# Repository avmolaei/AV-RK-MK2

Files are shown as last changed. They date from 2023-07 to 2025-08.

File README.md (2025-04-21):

# AV-RK-MK2

The AV-RK MK II is the second iteration of the AVlabs [AV-RK MK I](https://github.com/avmolaei/AV-RK-MK1), the AVlabs "Redox Styled" Mechanical Keyboard.
![AV-RK MK 2](img/1.png

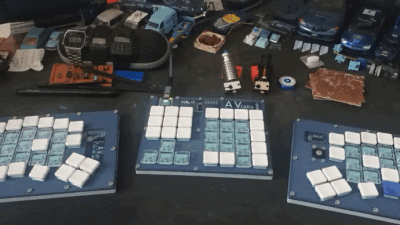
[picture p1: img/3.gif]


The AV-RK MK II uses a 3D printed body, Kailh Choc Switches and is based on a XIAO SAMD21 board. There is only one MCU running the whole thing: switches are connected to IO expanders (PCA9505), that share an I2C bus, which is propagated through magnetic pogo pins (like the Apple MagSafe connector). 
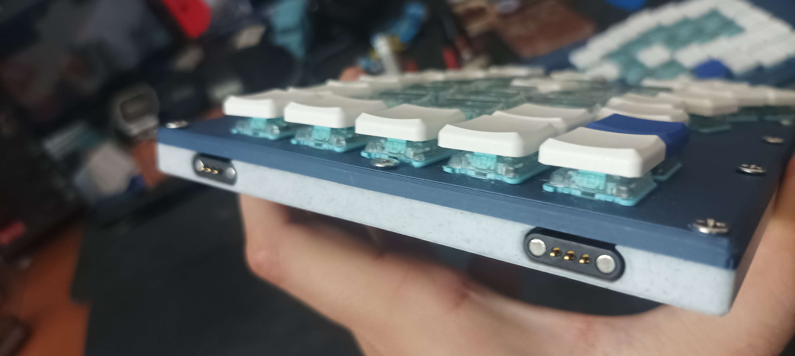
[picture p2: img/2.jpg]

The goal was also to make an even thinner keyboad than the MK I for more comfort: 
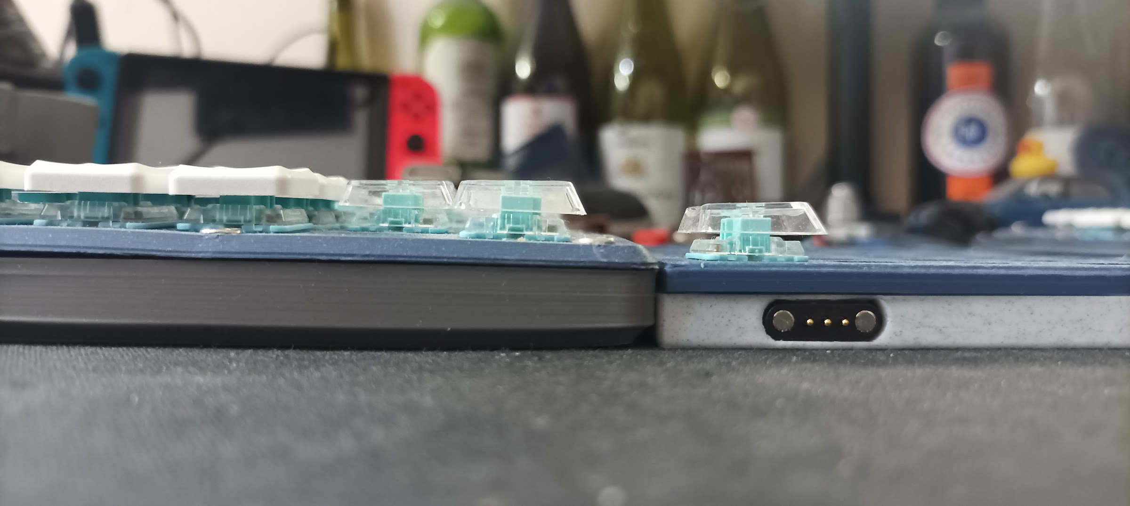
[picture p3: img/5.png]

(the MK I on the left, and the MK II on the right)
  
The [AV-RK-MK I](https://github.com/avmolaei/AV-RK-MK1) and the [AV-KO1](https://github.com/avmolaei/AV-KO1/) are both handwired keyboards (Expaination in details in the AV-KO1 repo). While handwire is easy to get started on, it has a few problems:

 - The switches are held to the top plate with nothing but friction, and over time (especially if you use "tall" switch+keycap combos, the switch can get loose, or if you knock the board it can get the switch to "pop out":
 - 
 - If you don't plan out your tolerances and screw holes correctly, the top plate will "bow", and make a gap between the plate and body as there is nothing to keep it from bowig
 - Soldering 100 switches and diodes is a good exercise but it is a bit tedious...
 - As most shift registers/IO Expanders are small SMD parts, most "sane" Handwire builds have multiple microcontrôleurs, which is not always ideal. 

The 3 parts connect together with cool magnetic pogo pins. these pogo pins allow a modular layout, i.e if the pogo pins are wired identically and laid out symetrically, you can put the numpad on the left, in the middle, on the right, or even add modules: as long as it communicates with I2C. The architecture of the AV-RK-MK2 is as follows:
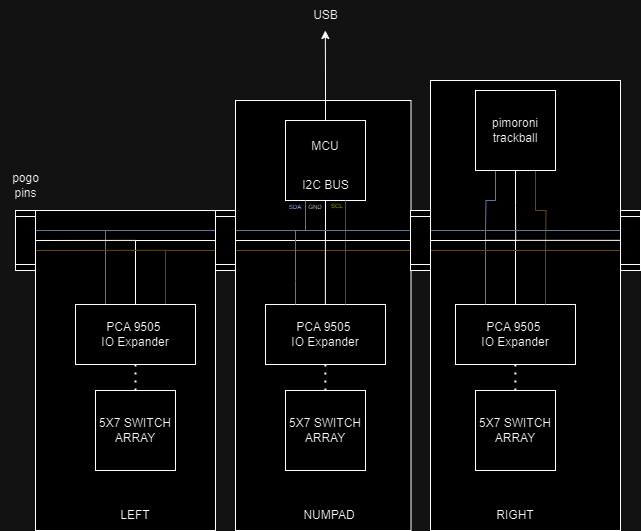
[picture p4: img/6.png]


 Here the goal was to design and build my "endgame" definition of a keyboard. It had to be "redox styled", it had to have kailh choc robins, and it had to have PCBs!
 
 Indeed, while PCBs do imply a higher cost, they make assembly super simple and allow for more complex layout! The PCA9505 couldn't have been used without the PCBS. As our keyboard has 3 parts, it has 3 PCBs:
 

The PCBs are pretty simple: they are just a bunch of switches connected to the PCA input pins, and the PCA's I2C line being distributed to pins which will be connected to the pogo pins. The middle PCB (numpad) has a small cutout for the XIAO board, and the right PCB has a cutout made to fit a pimoroni trackball, or any other I2C device you would want. 

Available below are:

CAD files: Fusion 360 source and STLs for 3D printed parts

FIRMWARE: the arudino code that runs the keyboard

PCB files: gerbers and boms

MODULES: modules, duh.

`//TODO: shit to fix and/or add
`

PCBs: on all PCBs, the I2C/PWR lines are too close to the edge. On the right PCB, the pins for the pimoroni trackball are reversed, which requires an annoying bodge.

Technically speaking, I2C is not rated for hot swap. In a future iteration, the PCBs **SHOULD** integrate a TCA4307 from TI, a simple I2C buffer to allow for a less buggy kb if the stack is moved from arduino to TinyUSB/from scratch

FIRMWARE: needs to be ported from SAMD21 core to NRF52840. Also, need to fix trackball precision issue. Also, the USB HID lib needs to go from Keyboard.h to TinyUSB.

CAD: maybe enhance aesthetics for the top plate? also need to make some sort of alignement system for the pogo pins, sometimes when docking/undocking modules the pins may short and require a MCU reset

`MODULES:`

**__AV-RK SENSOR MODULE__**: It has a thin OLED display and a square one. It will have an RTC, a humidity/temp sensor and a heartbeat sensor, all that on the I2C BUS. V2 of this module will inclue an independant MCU so the code is not cluttering the main keyboard code. AAAAAAAAA

**__AV-RK MOUSE CHARGER__**: it will have a tiny arduino nano inside, and will recieve commands based on keyboard shortcuts on the I2C bus. The "independant" arduino will trigger LEDs for caps lock/num lock/scroll lock, and will control a tiny servo-actuated arm that shows pogo pins to charge the mouse overnight. The mouse needs to be modified with a USB connector soldered to pogo pins. 

Sensors have been designed, made; all is left is to integrate them in the main code. 

A better, more sensible solution would be to embedd a small low power MCU (e.g: arduino nano) in each module, and make them use a "protocol", where Fn + [NUMPAD NUMBER] sends a set command and the module is programmed to understand the command, instead of integrating everything in the main keyboard code, making a messs. 
2025: i kinda forgot about the modules, after 1 yeaer and half. The only one that sees regular use is the mouse charger.

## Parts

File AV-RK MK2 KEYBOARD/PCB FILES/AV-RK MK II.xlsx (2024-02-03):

where to get the shit | cost
Keycaps and switches (splitkb.com) | 131.41 €
MCU board, pogo pins, and other shit (amazon) | 148.74 €
3D printer filament (amazon) | 45.00 €
LCSC/JLCPCB: numpad | 92.32 €
LCSC/JLCPCB: left + right | 183.43 €
TOTAL | 600.90 €

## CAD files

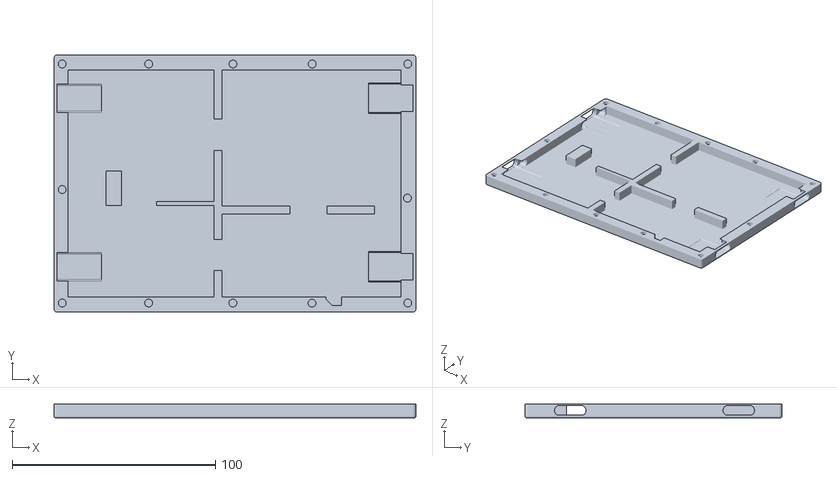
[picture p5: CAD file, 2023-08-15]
AV-RK MK2 KEYBOARD/CAD FILES/AV_RK_MK_II_CAD/left/v2/bottom (1).stl
178.3 x 126.7 x 7.00

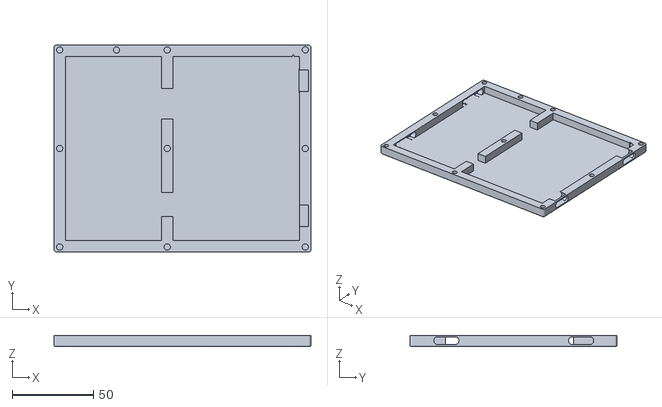
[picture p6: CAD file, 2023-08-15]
AV-RK MK2 KEYBOARD/CAD FILES/AV_RK_MK_II_CAD/numpad/stl/v2/bottom.stl
158.3 x 127.5 x 7.00

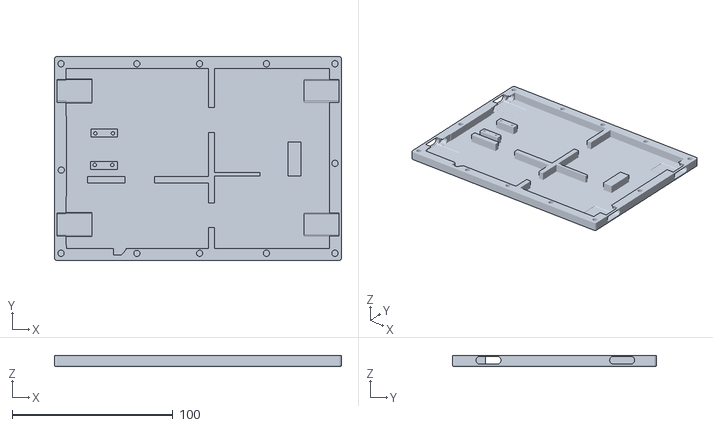
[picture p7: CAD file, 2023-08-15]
AV-RK MK2 KEYBOARD/CAD FILES/AV_RK_MK_II_CAD/right/v2/bottom.stl
178.3 x 126.7 x 7.00

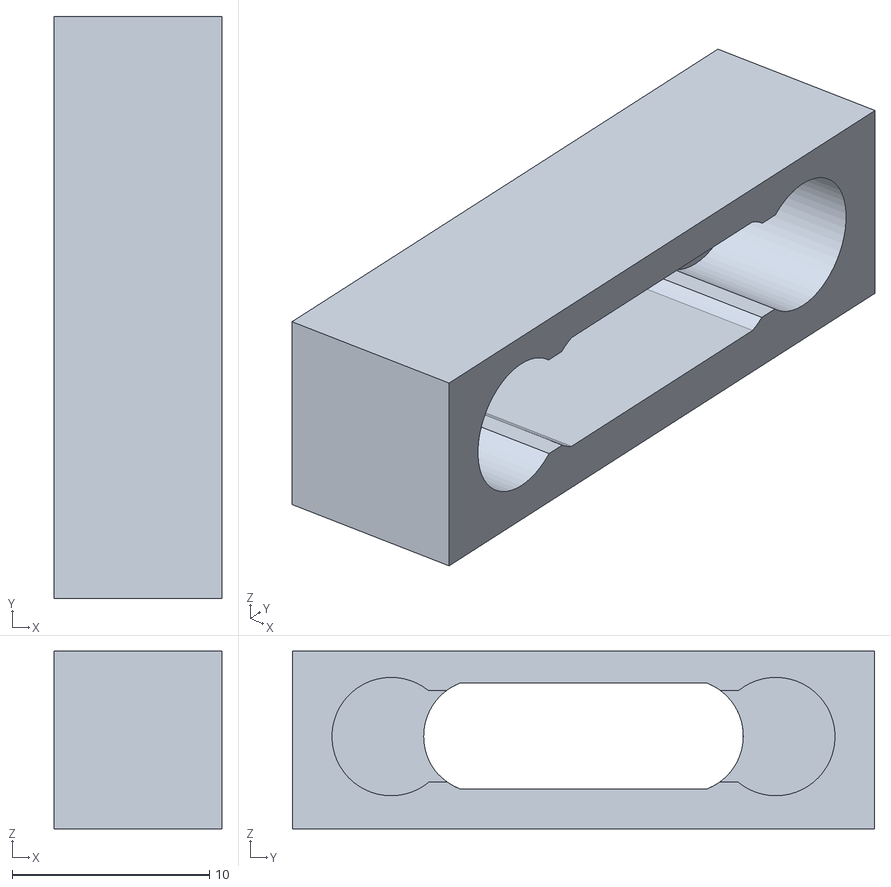
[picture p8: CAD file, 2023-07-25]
AV-RK MK2 KEYBOARD/CAD FILES/tests/Corps42.stl
8.50 x 29.5 x 9.00

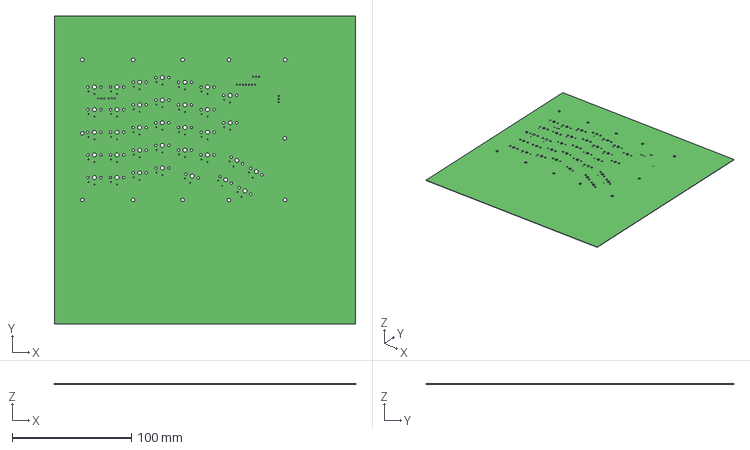
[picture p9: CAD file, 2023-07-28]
AV-RK MK2 KEYBOARD/PCB FILES/LEFT/EDA FILES/Altium/left.step
252.9 x 258.6 x 0.411 mm

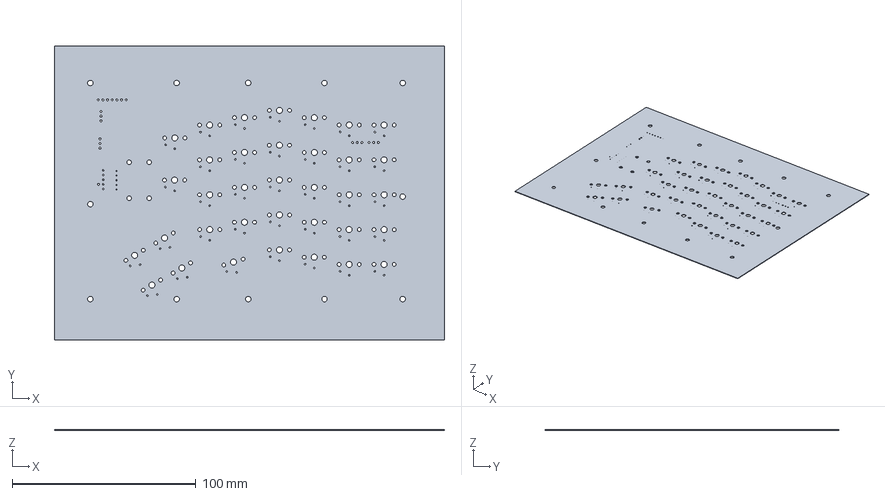
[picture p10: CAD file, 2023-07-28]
AV-RK MK2 KEYBOARD/PCB FILES/RIGHT/EDA FILES/Altium/PCB_RIGHT_AV-RK MK II_2023-07-27.step
212.5 x 160.2 x 0.411 mm

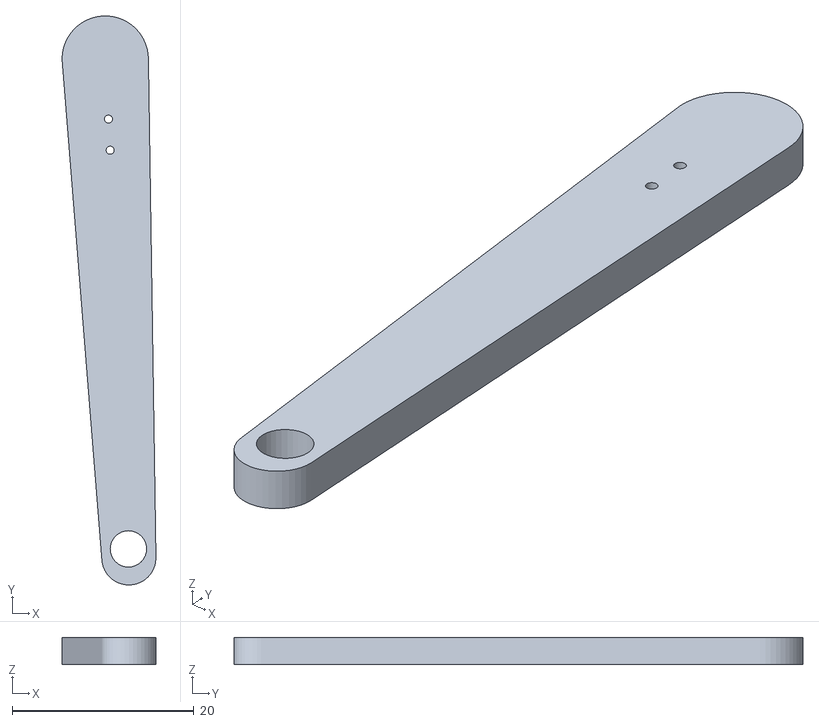
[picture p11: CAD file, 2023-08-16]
AV-RK MK2 MODULE - MOUSE CHARGER/CAD FILES/link.stl
10.3 x 62.6 x 3.00

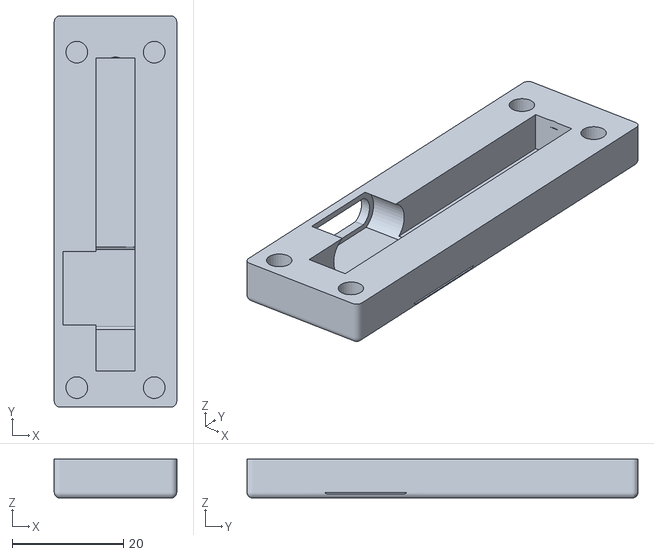
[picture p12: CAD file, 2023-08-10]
AV-RK MK2 MODULE - MOUSE CHARGER/CAD FILES/mouse pogo pin adapter/moving part/bottom.stl
22.0 x 70.2 x 7.00

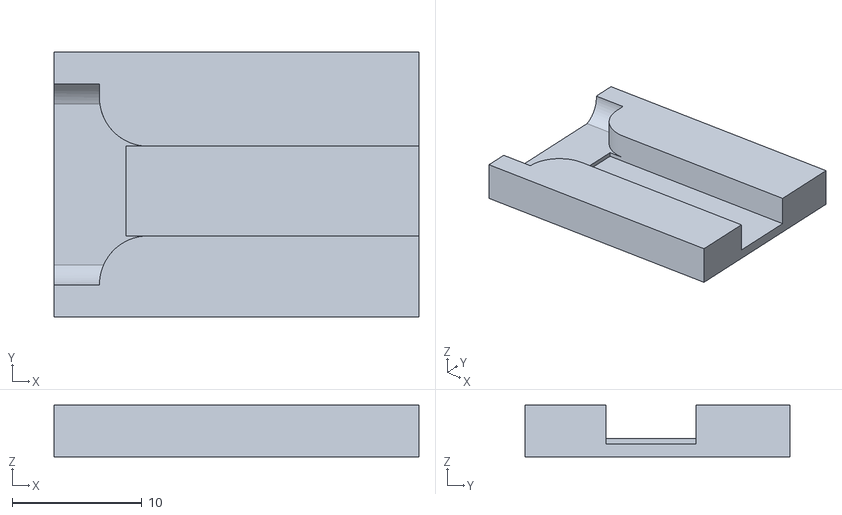
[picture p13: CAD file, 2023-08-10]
AV-RK MK2 MODULE - MOUSE CHARGER/CAD FILES/mouse pogo pin adapter/top.stl
28.1 x 20.4 x 4.00

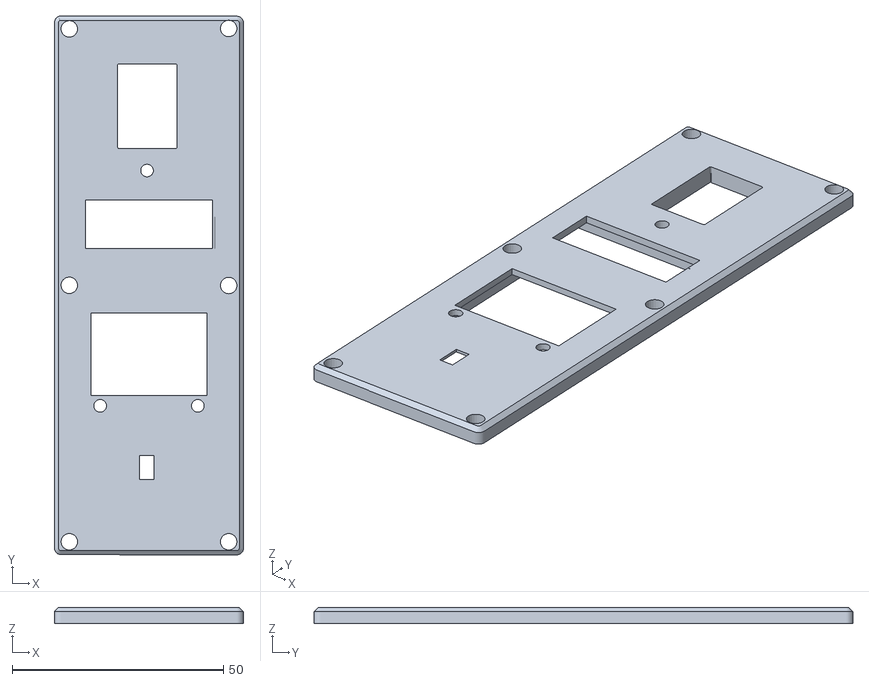
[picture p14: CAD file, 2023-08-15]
AV-RK MK2 MODULE - SENSOR SCREEN/3D PRINTED PARTS/GCODE/top (3).stl
44.7 x 127.4 x 3.80

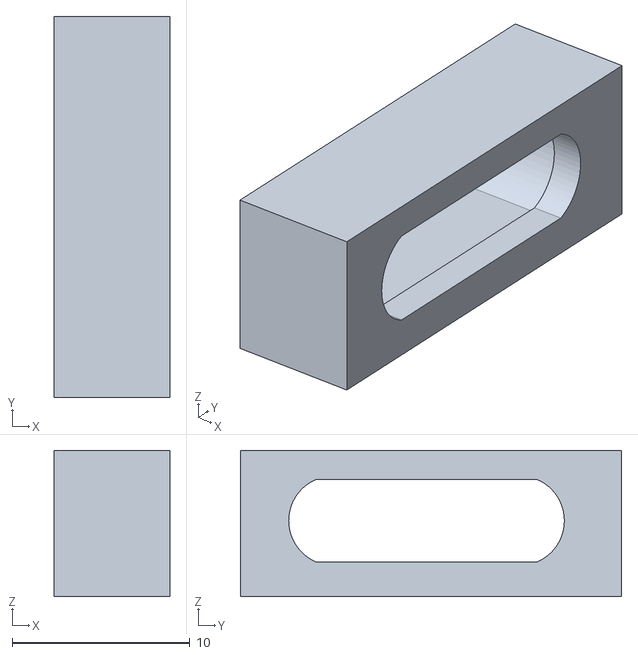
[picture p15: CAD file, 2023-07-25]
AV-RK MK2 KEYBOARD/CAD FILES/tests/test pogo.stl
6.50 x 21.4 x 8.21

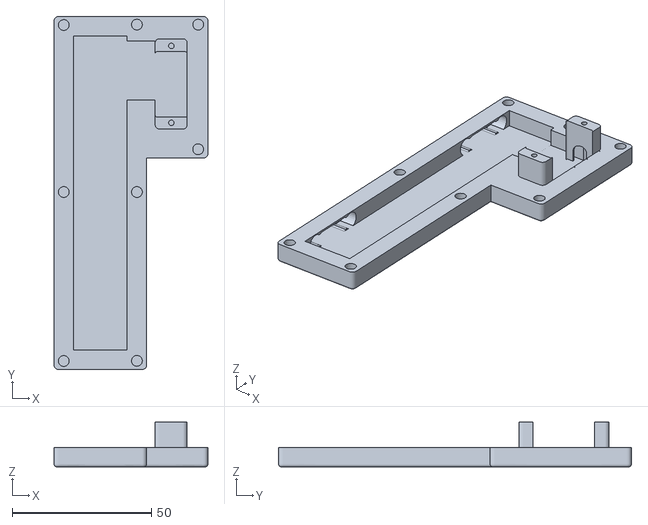
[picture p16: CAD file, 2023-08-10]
AV-RK MK2 MODULE - MOUSE CHARGER/CAD FILES/bottom (3).stl
55.2 x 126.7 x 16.0

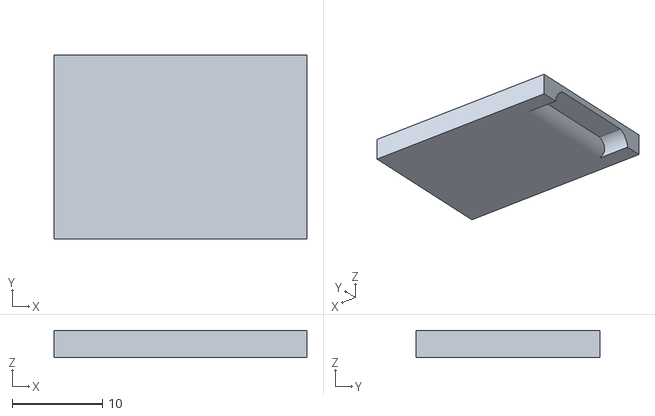
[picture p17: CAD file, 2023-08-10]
AV-RK MK2 MODULE - MOUSE CHARGER/CAD FILES/mouse pogo pin adapter/bottom (2).stl
28.1 x 20.4 x 3.00

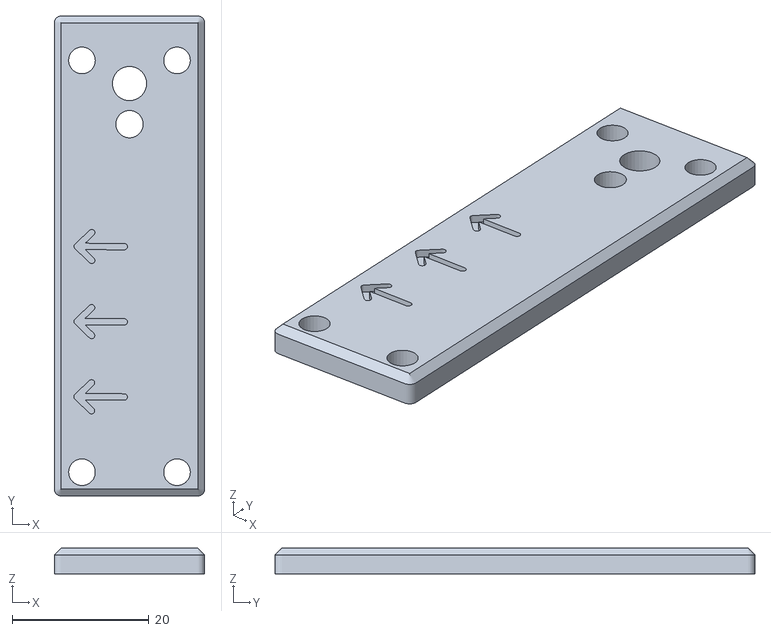
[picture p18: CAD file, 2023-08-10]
AV-RK MK2 MODULE - MOUSE CHARGER/CAD FILES/mouse pogo pin adapter/moving part/TOP.stl
22.0 x 70.2 x 3.80

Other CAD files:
AV-RK MK2 MODULE - SENSOR SCREEN/3D PRINTED PARTS/STL/TOP.stl
AV-RK MK2 MODULE - SENSOR SCREEN/3D PRINTED PARTS/top (3).stl
AV-RK MK2 MODULE - SENSOR SCREEN/3D PRINTED PARTS/STL/BOTTOM.stl
AV-RK MK2 KEYBOARD/CAD FILES/tests/test pogo m.stl
AV-RK MK2 KEYBOARD/CAD FILES/AV_RK_MK_II_CAD/left/v1/bottom (1).stl
AV-RK MK2 KEYBOARD/CAD FILES/AV_RK_MK_II_CAD/left/v1/left drawing.dxf
AV-RK MK2 KEYBOARD/CAD FILES/AV_RK_MK_II_CAD/left/v1/top (1).stl
AV-RK MK2 KEYBOARD/CAD FILES/AV_RK_MK_II_CAD/left/v1/top window.stl
AV-RK MK2 KEYBOARD/CAD FILES/AV_RK_MK_II_CAD/numpad/stl/v1/bottom.stl
AV-RK MK2 KEYBOARD/CAD FILES/AV_RK_MK_II_CAD/numpad/stl/v1/top.stl
AV-RK MK2 KEYBOARD/CAD FILES/AV_RK_MK_II_CAD/right/v1/bottom (1) (1).stl
AV-RK MK2 KEYBOARD/CAD FILES/AV_RK_MK_II_CAD/right/v1/top (1) (1).stl
AV-RK MK2 MODULE - MOUSE CHARGER/CAD FILES/top (2).stl

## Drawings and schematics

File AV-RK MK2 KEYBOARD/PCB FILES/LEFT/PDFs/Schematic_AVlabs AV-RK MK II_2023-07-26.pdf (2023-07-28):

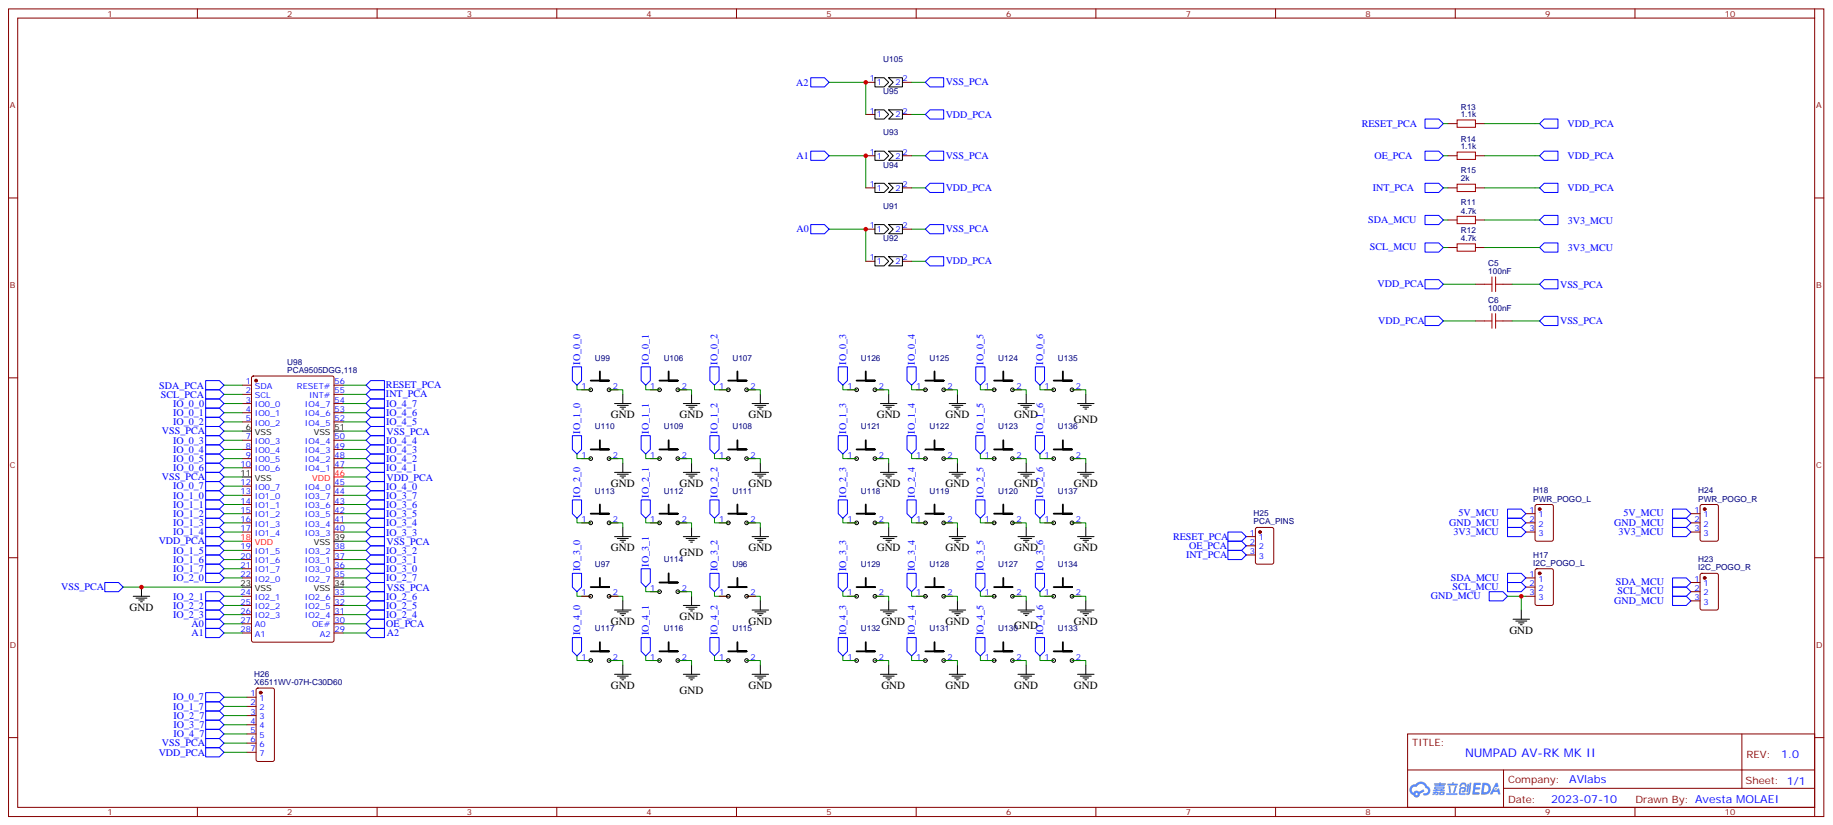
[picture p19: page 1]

Drawn By: Avesta MOLAEI

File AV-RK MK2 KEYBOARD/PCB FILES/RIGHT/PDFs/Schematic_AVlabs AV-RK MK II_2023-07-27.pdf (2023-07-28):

H31 1 2 2 3 3 4 4 5 5 6 6 7 7

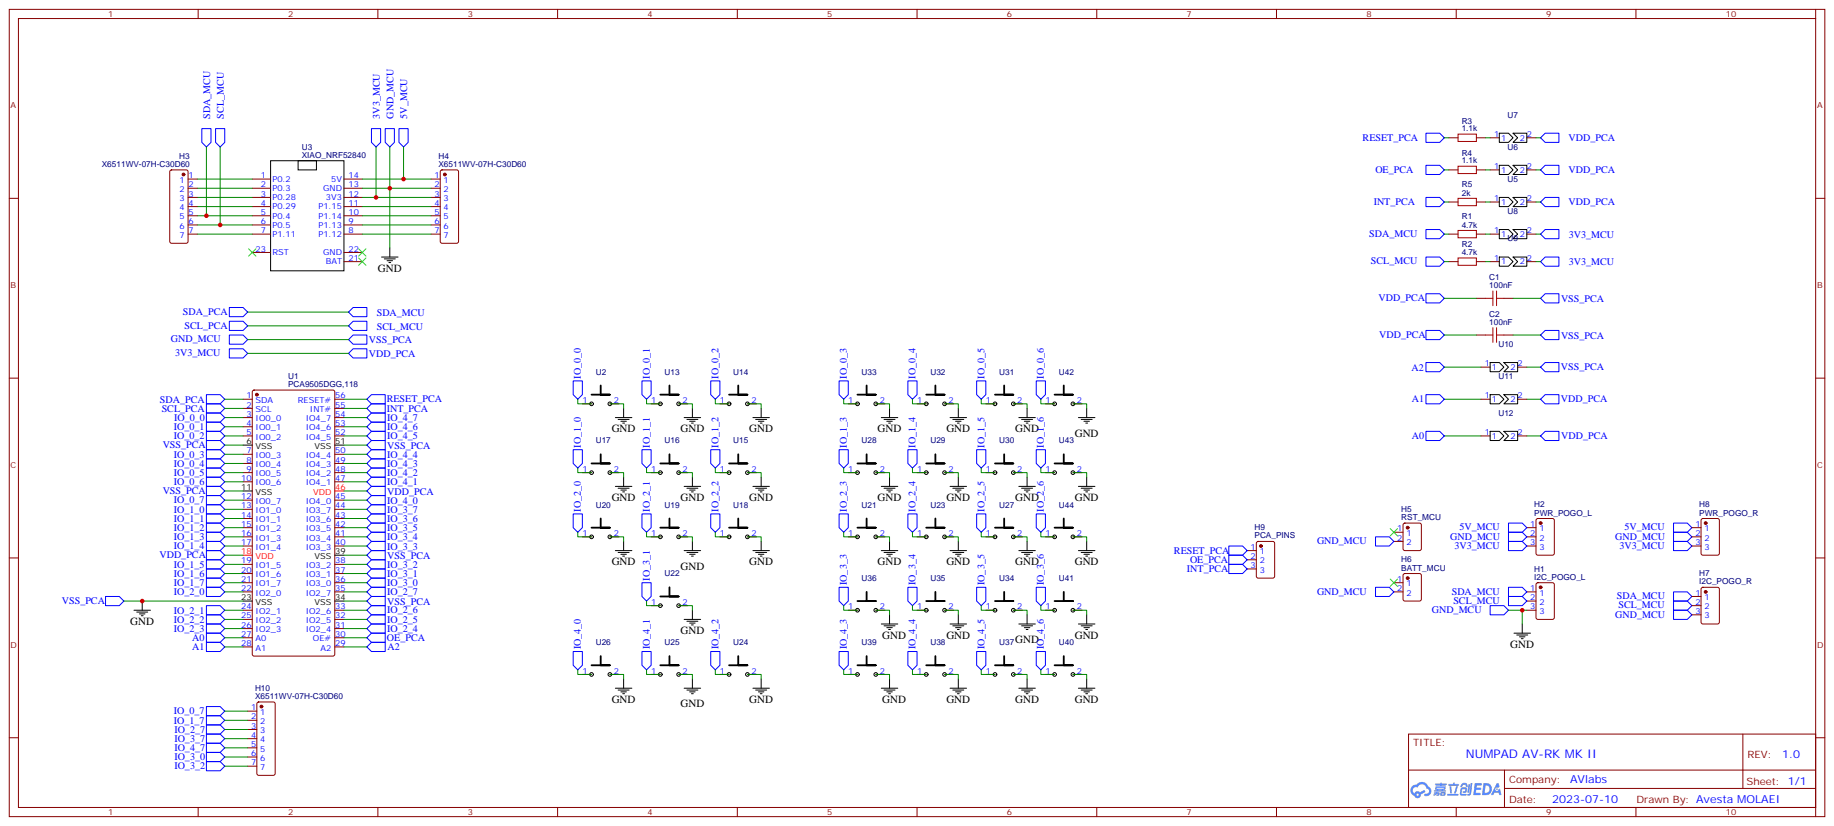
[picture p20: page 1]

Drawn By: Avesta MOLAEI

A1 28 A2 29 OE# 30 IO2_4 31 IO2_5 32 IO2_6 33 VSS 34 IO2_7 35 IO3_0 36 IO3_1 37 IO3_2 38 VSS 39 IO3_3 40 IO3_4 41 IO3_5 42 IO3_6 43 IO3_7 44 IO4_0 45 VDD 46 IO4_1 47 IO4_2 48 IO4_3 49 IO4_4 50 VSS 51 IO4_5 52 IO4_6 53 IO4_7 54 INT# 55 RESET# 56

H11 1

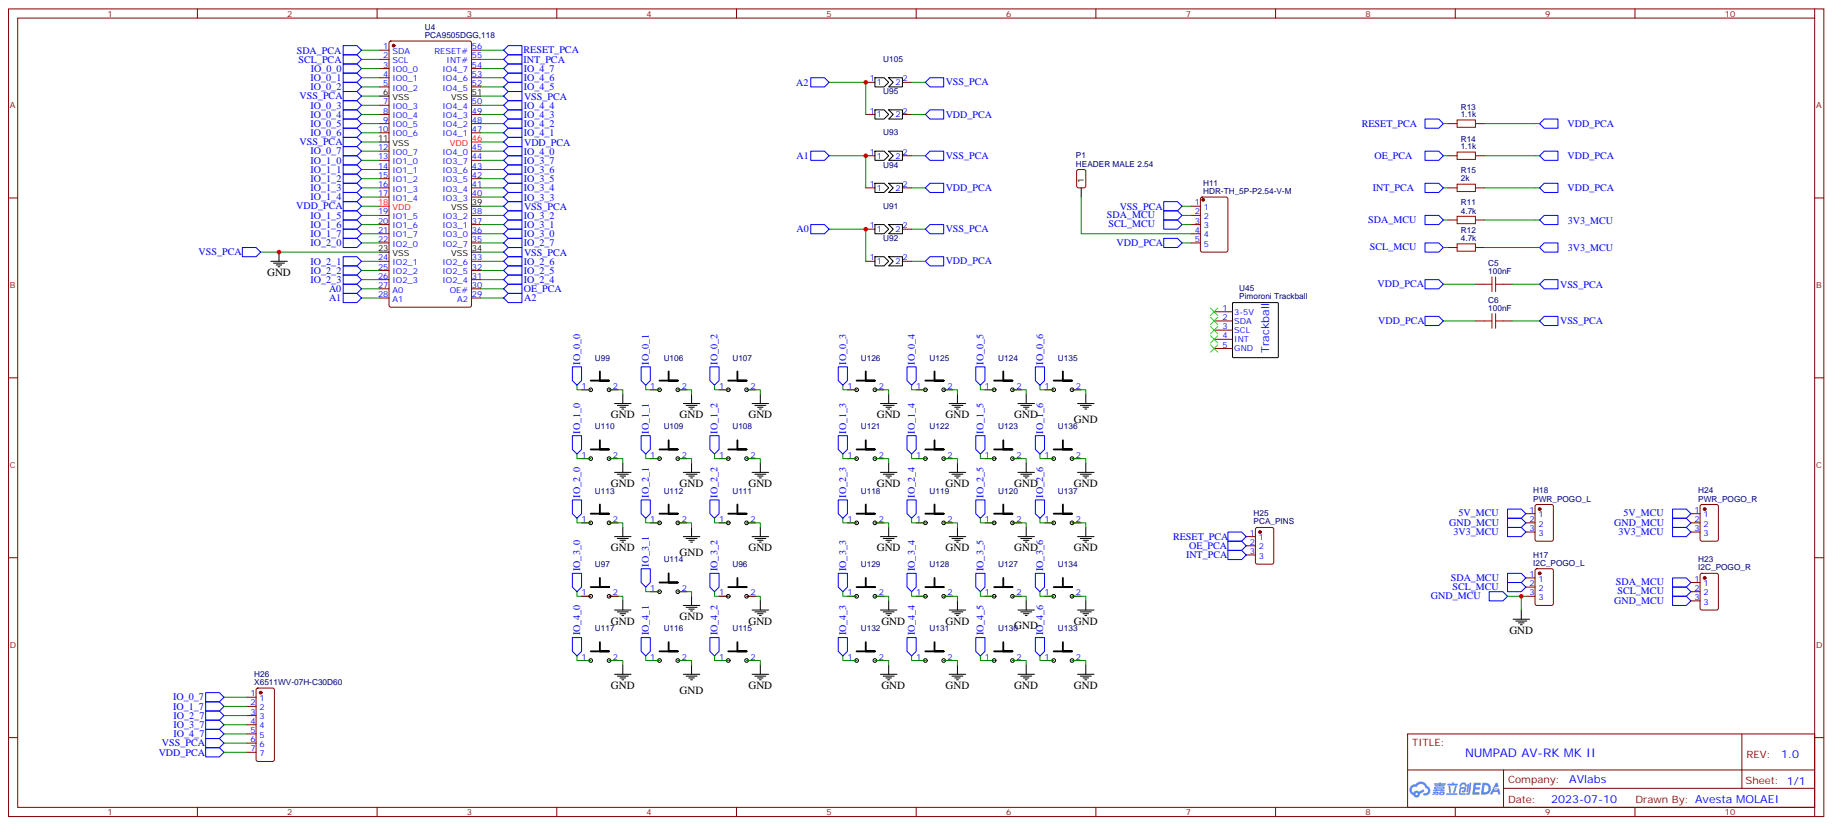
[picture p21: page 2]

Drawn By: Avesta MOLAEI

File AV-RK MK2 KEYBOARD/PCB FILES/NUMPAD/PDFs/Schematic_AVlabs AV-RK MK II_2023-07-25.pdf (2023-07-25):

H31 1 2 2 3 3 4 4 5 5 6 6 7 7


Drawn By: Avesta MOLAEI

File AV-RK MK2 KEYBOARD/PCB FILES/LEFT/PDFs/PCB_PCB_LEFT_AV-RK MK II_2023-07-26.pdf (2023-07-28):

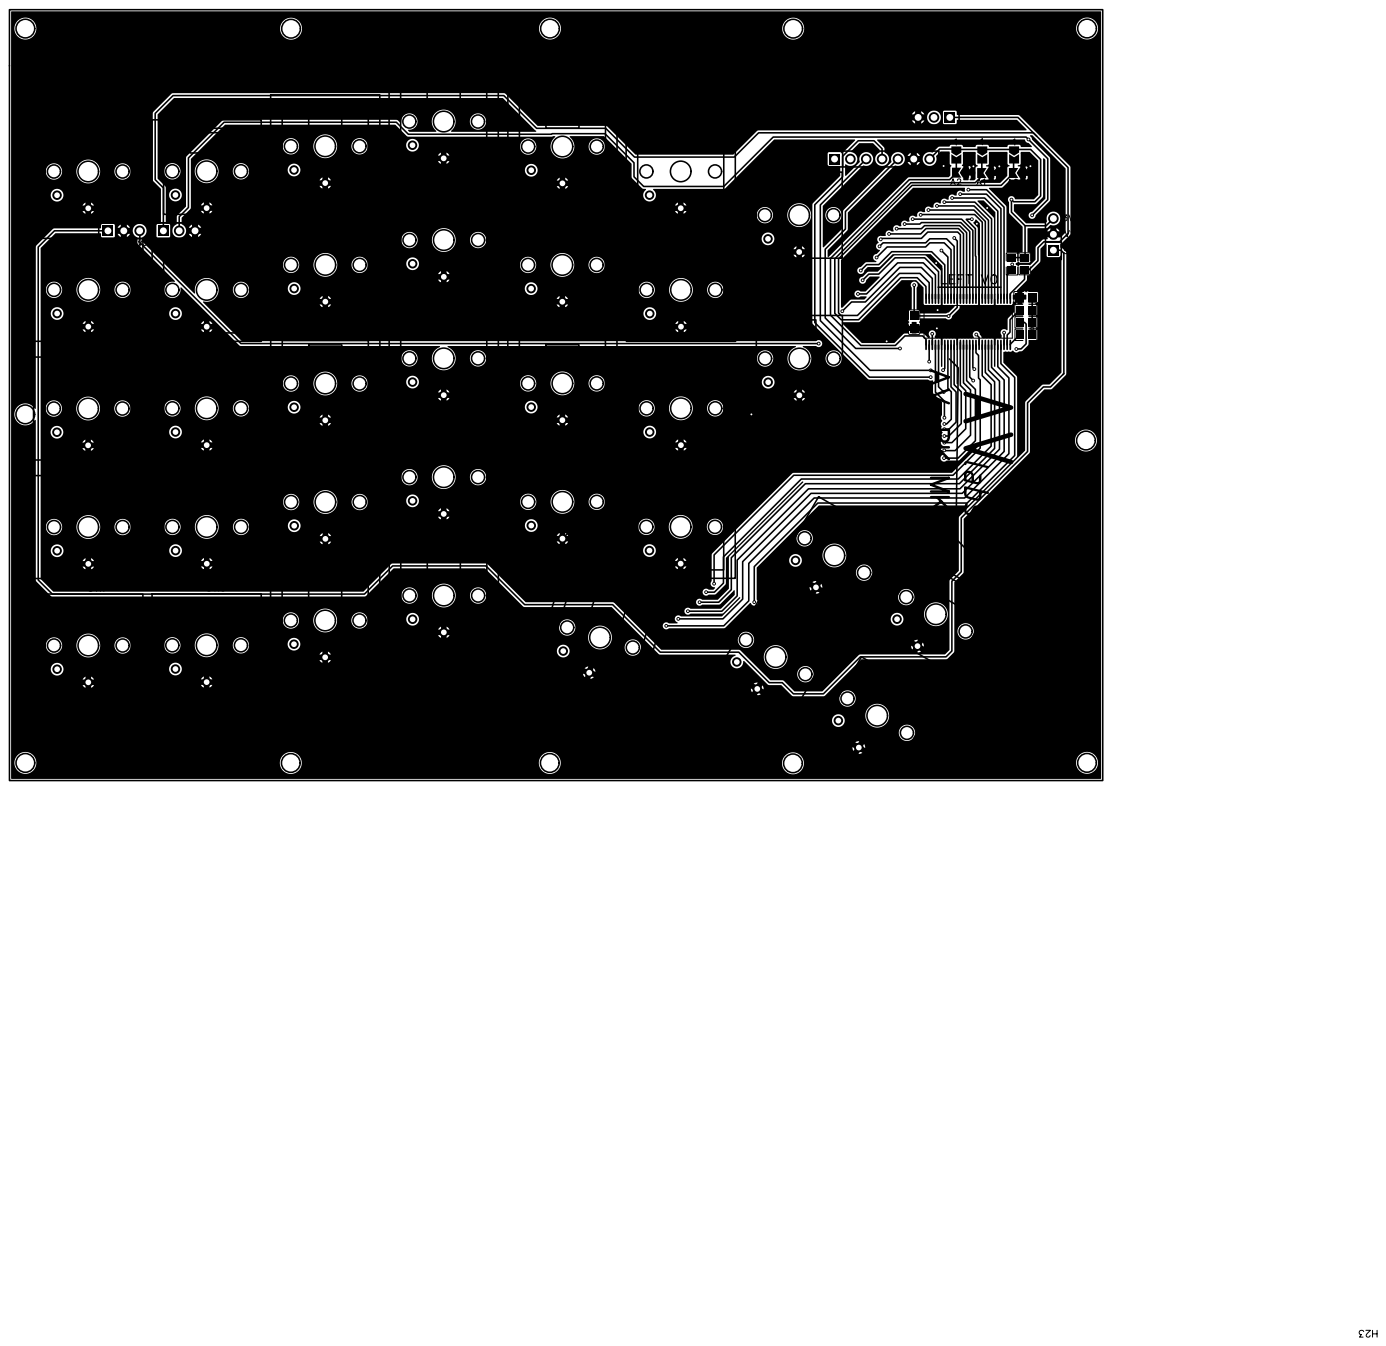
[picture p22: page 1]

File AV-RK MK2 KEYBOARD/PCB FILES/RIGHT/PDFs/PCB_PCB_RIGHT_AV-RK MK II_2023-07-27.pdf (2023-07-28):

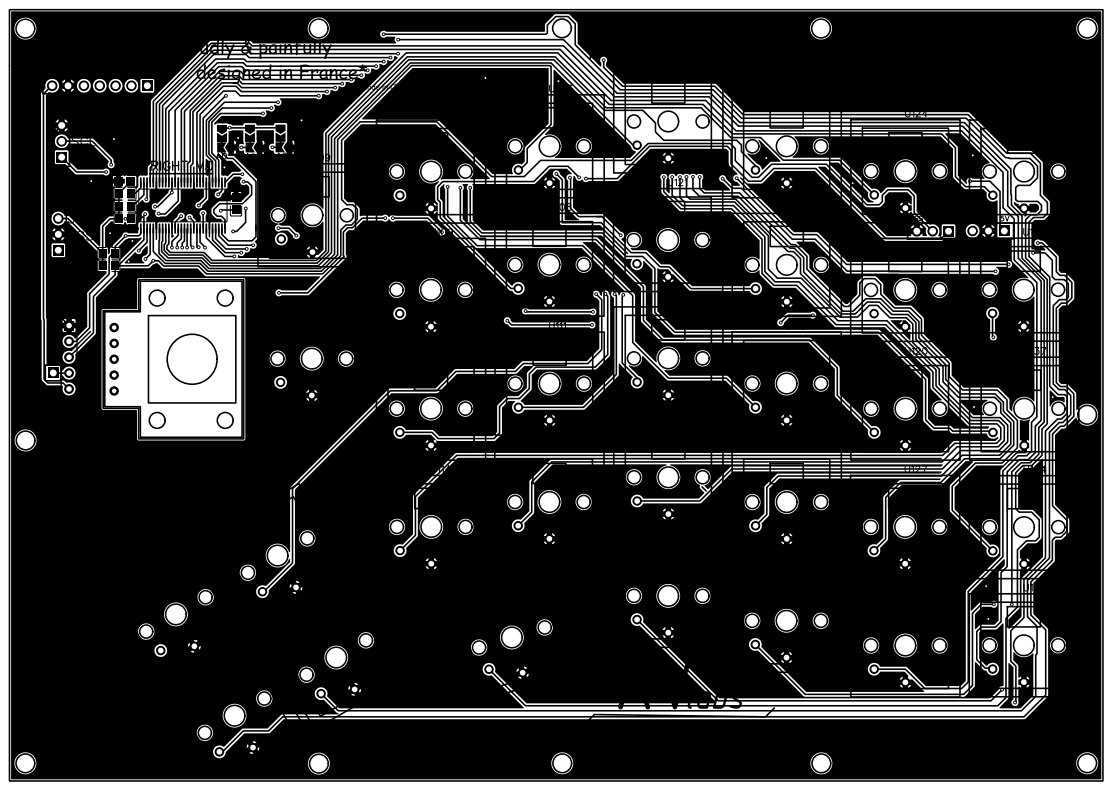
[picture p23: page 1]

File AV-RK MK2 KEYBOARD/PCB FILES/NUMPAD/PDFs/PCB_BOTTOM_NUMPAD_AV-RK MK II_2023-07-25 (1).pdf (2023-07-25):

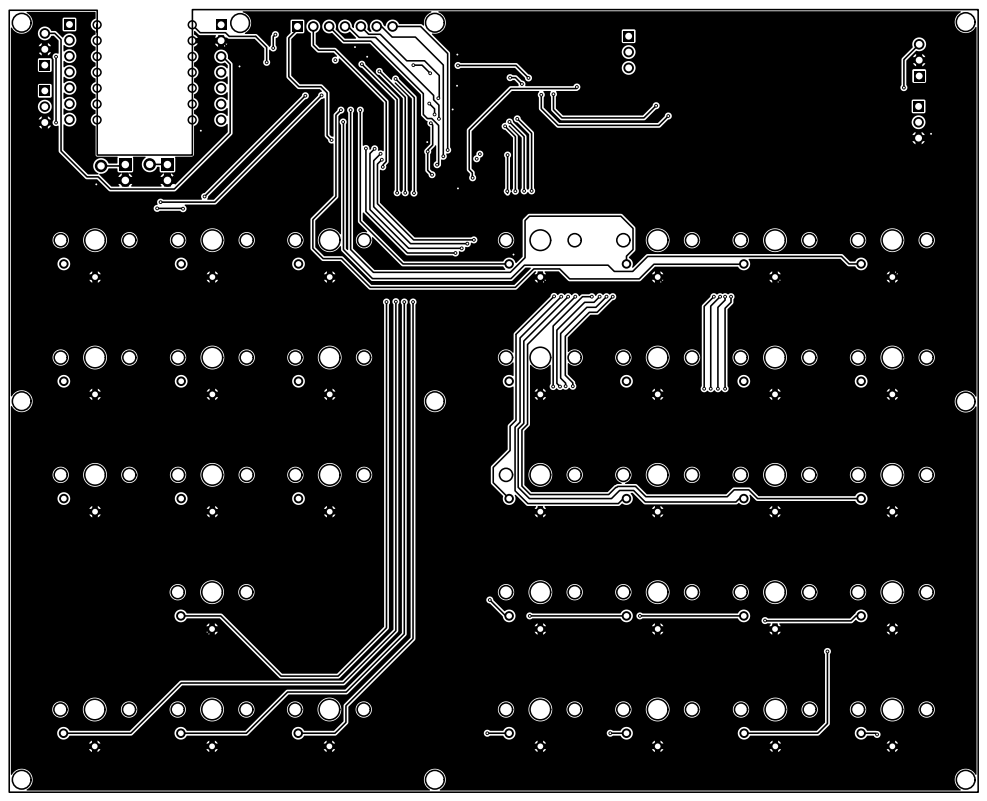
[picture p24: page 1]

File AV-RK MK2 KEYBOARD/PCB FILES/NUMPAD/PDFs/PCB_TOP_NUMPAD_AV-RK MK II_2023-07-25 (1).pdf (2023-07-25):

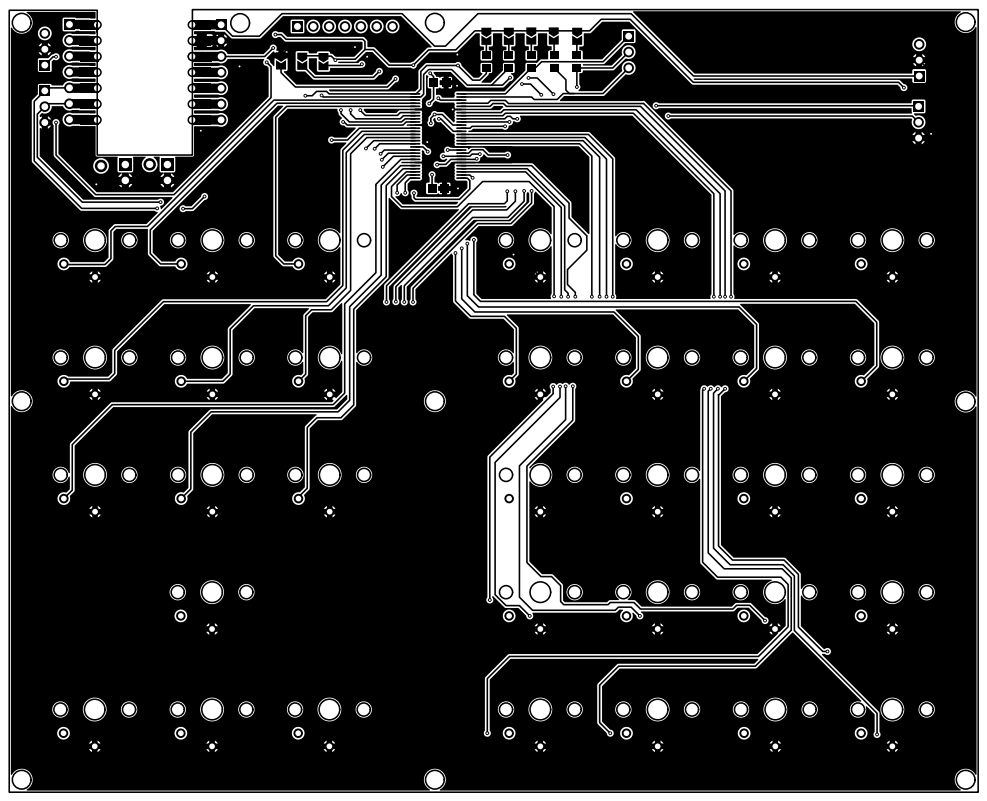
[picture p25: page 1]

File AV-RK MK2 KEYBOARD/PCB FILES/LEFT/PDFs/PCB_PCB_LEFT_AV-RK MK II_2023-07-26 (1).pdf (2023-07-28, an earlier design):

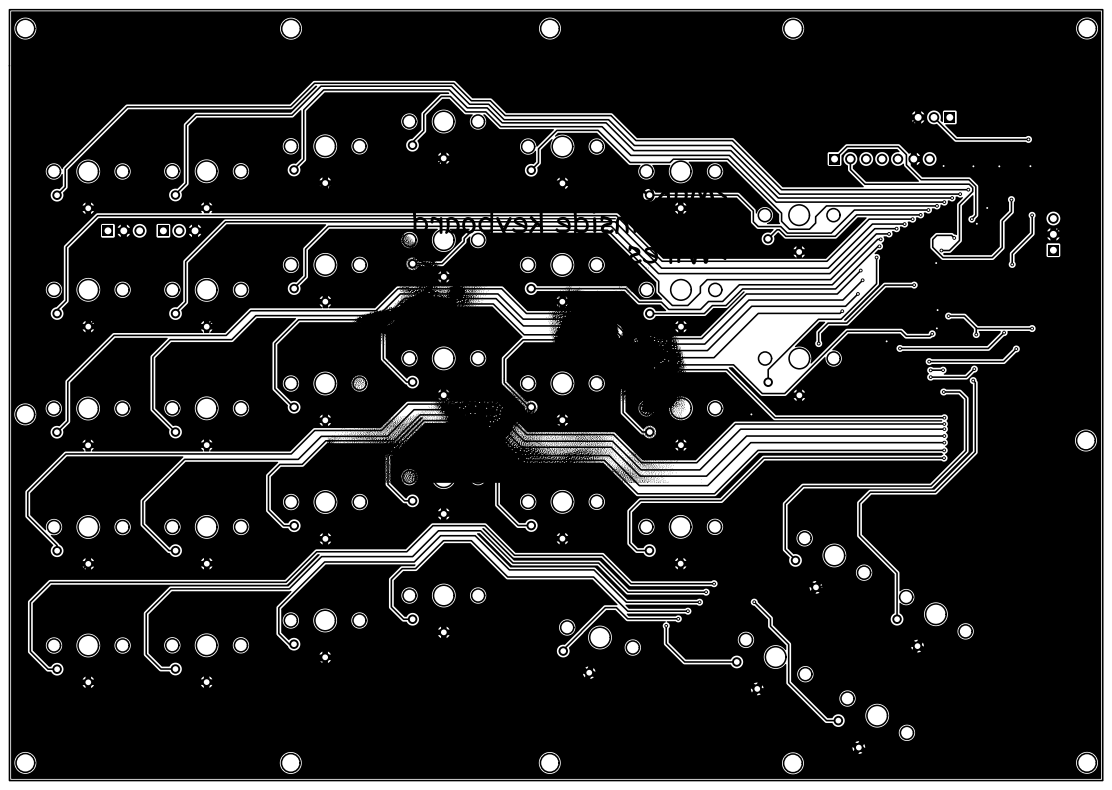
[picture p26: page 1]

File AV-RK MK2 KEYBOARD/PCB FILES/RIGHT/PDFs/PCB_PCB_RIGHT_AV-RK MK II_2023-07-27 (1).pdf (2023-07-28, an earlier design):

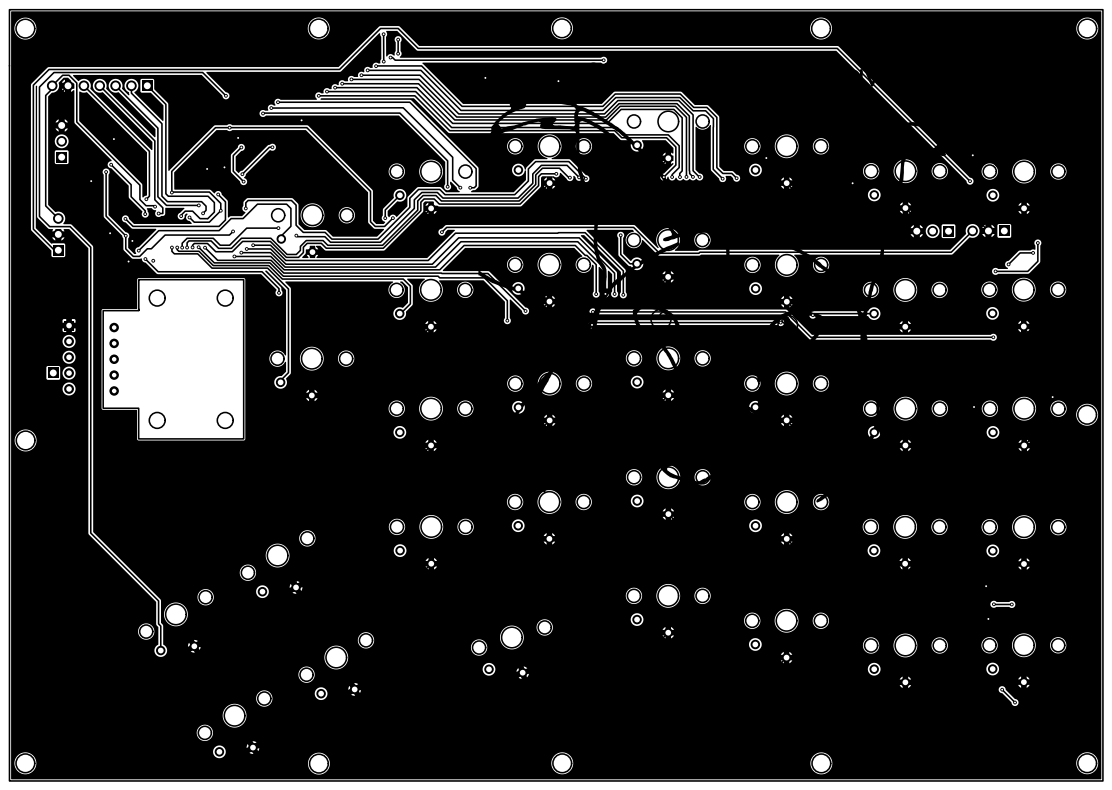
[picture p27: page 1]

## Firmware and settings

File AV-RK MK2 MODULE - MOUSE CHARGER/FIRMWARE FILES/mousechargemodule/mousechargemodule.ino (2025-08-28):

/*-------------------------------------------------------------------------
AVLABS_AV_RK_MKII_ArmModule.ino, I2C slave firmware for the charging arm.
    Copyright (C) 2025  AVlabs

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
    You should have received a copy of the GNU General Public License
    along with this program.  If not, see <https://www.gnu.org/licenses/>.
-------------------------------------------------------------------------*/


//------------------LIBRARIES------------------
//Wire:   I2C slave communications
//Servo:  Standard hobby servo control
//EEPROM: Persist last known arm position (angle)
#include <Wire.h>
#include <Servo.h>
#include <EEPROM.h>
//--------------------------------------------------------------------------------------------------------


//------------------DEFINES------------------------------------------------------
//I2C slave address (must match master NANO_I2C_ADDRESS)
#define ARM_I2C_ADDRESS         8

//Pins
#define SERVO_PIN               9       // PWM-capable pin for servo signal
#define STATUS_LED_PIN          LED_BUILTIN

//Servo and motion config
#define ANGLE_MIN               3       // degrees
#define ANGLE_MAX               250     // degrees

//Set true for eased movement; false for immediate set
#define USE_SMOOTH_MOTION       false
#define SMOOTH_STEP_DEG         2       // degrees per step when smoothing
#define SMOOTH_STEP_DELAY_MS    15      // ms between steps

//Auto-detach to avoid buzzing/heat when idle
#define DETACH_AFTER_IDLE_MS    600

//EEPROM address for persisted angle (1 byte)
#define EEPROM_ADDR_ANGLE       0
//--------------------------------------------------------------------------------------------------------


//--------------------VARS---------------------
//Servo control
Servo servoArm;
bool  servoAttached           = false;

//Angles
uint8_t currentAngle          = 0;      // physical angle last written to servo
uint8_t targetAngle           = 0;      // requested angle from master

//Timers
unsigned long lastMoveTime    = 0;      // last time we moved or received a command
unsigned long lastStepTime    = 0;      // last time we performed a smooth step
//---------------------------------------------


//------------------PROTOTYPES------------------
void onI2CReceive(int numBytes);
void attachIfNeeded();
void detachIfIdle();
uint8_t clampAngle(int v);
void setAngleImmediate(uint8_t deg);
void setAngleSmooth(uint8_t deg);
void saveAngleToEEPROM(uint8_t deg);
uint8_t loadAngleFromEEPROM();
//---------------------------------------------


//------------------FUNCTIONS------------------
/**
 * @brief setup(), init function
*/
void setup() {
  pinMode(STATUS_LED_PIN, OUTPUT);
  digitalWrite(STATUS_LED_PIN, LOW);

  //Restore last known angle from EEPROM and apply once
  currentAngle = loadAngleFromEEPROM();
  targetAngle  = currentAngle;

  attachIfNeeded();
  servoArm.write(currentAngle);
  lastMoveTime = millis();

  //I2C slave init
  Wire.begin(ARM_I2C_ADDRESS);
  Wire.onReceive(onI2CReceive);

  //Blink to signal ready
  digitalWrite(STATUS_LED_PIN, HIGH);
  delay(60);
  digitalWrite(STATUS_LED_PIN, LOW);
}


/**
 * @brief loop(), infinite loop function
*/
void loop() {
  //Handle smooth motion if enabled
  if (USE_SMOOTH_MOTION && currentAngle != targetAngle) {
    unsigned long now = millis();
    if (now - lastStepTime >= SMOOTH_STEP_DELAY_MS) {
      lastStepTime = now;

      int diff = (int)targetAngle - (int)currentAngle;
      int step = (diff > 0) ? SMOOTH_STEP_DEG : -SMOOTH_STEP_DEG;

      if (abs(diff) <= SMOOTH_STEP_DEG) {
        currentAngle = targetAngle;     // snap to target when close
      } else {
        currentAngle = clampAngle((int)currentAngle + step);
      }

      attachIfNeeded();
      servoArm.write(currentAngle);
      lastMoveTime = now;

      if (currentAngle == targetAngle) {
        saveAngleToEEPROM(currentAngle);
      }
    }
  }

  //Detach after inactivity to reduce noise and power
  detachIfIdle();
}


/**
 * @brief I2C receive callback, reads last byte as target angle
 * 
 * The keyboard master sends a single byte command (0..180).
 * We clamp to [ANGLE_MIN..ANGLE_MAX], ignore duplicates (idempotent),
 * and move the servo immediately (or smoothly if enabled).
*/
void onI2CReceive(int numBytes) {
  if (numBytes <= 0) return;

  int lastVal = -1;
  while (Wire.available()) {
    lastVal = Wire.read(); // consume all, keep last
  }
  if (lastVal < 0) return;

  uint8_t requested = clampAngle(lastVal);

  //Update activity time so auto-detach doesn't trigger immediately
  lastMoveTime = millis();

  //Idempotent: if same as current target, no redundant motion
  if (requested == targetAngle) return;

  targetAngle = requested;

  //Status flash
  digitalWrite(STATUS_LED_PIN, HIGH);

  if (USE_SMOOTH_MOTION) {
    setAngleSmooth(targetAngle);  // loop() takes care of steps
  } else {
    setAngleImmediate(targetAngle);
  }

  digitalWrite(STATUS_LED_PIN, LOW);
}


/**
 * @brief Attach servo if not already attached
*/
void attachIfNeeded() {
  if (!servoAttached) {
    servoArm.attach(SERVO_PIN, 500, 2600);
    servoAttached = true;
  }
}



/**
 * @brief Detach servo after an idle timeout to avoid buzzing/heat
*/
void detachIfIdle() {
  if (!servoAttached) return;
  unsigned long now = millis();
  if (now - lastMoveTime >= DETACH_AFTER_IDLE_MS) {
    servoArm.detach();
    servoAttached = false;
  }
}


/**
 * @brief Clamp helper for angles
*/
uint8_t clampAngle(int v) {
  if (v < ANGLE_MIN) return ANGLE_MIN;
  if (v > ANGLE_MAX) return ANGLE_MAX;
  return (uint8_t)v;
}


/**
 * @brief Set servo angle immediately and persist
*/
void setAngleImmediate(uint8_t deg) {
  attachIfNeeded();
  servoArm.write(deg);
  currentAngle = deg;
  lastMoveTime = millis();
  saveAngleToEEPROM(currentAngle);
}


/**
 * @brief Prepare a smooth movement to a target angle
 * 
 * loop() will handle stepping at SMOOTH_STEP_DELAY_MS intervals.
*/
void setAngleSmooth(uint8_t deg) {
  targetAngle  = clampAngle(deg);
  attachIfNeeded();
  lastStepTime = millis();
  lastMoveTime = millis();
}


/**
 * @brief Save current angle to EEPROM (wear-safe)
*/
void saveAngleToEEPROM(uint8_t deg) {
  if (EEPROM.read(EEPROM_ADDR_ANGLE) != deg) {
    EEPROM.update(EEPROM_ADDR_ANGLE, deg);
  }
}


/**
 * @brief Load last angle from EEPROM (validated)
*/
uint8_t loadAngleFromEEPROM() {
  uint8_t v = EEPROM.read(EEPROM_ADDR_ANGLE);
  return clampAngle(v);
}
//END

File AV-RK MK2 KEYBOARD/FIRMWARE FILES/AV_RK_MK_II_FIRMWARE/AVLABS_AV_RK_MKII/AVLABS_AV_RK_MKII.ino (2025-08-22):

/*-------------------------------------------------------------------------
AVLABS_AV_RK_MKII.ino, the firmware of the AV-RK MK II keyboard.
    Copyright (C) 2023  AVlabs (Avesta MOLAEI)

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
    You should have received a copy of the GNU General Public License
    along with this program.  If not, see <https://www.gnu.org/licenses/>.
-------------------------------------------------------------------------*/


//------------------LIBRARIES------------------
//PCA9505_9506.h: Lib for the NXP PCA9505 IO Expander through I2C
//Keyboard.h:     Classic Arduino Keyboard lib
//Wire, Mouse and Pimoroni libs for the trackball
#include <PCA9505_9506.h>
#include <pimoroniTrackball.h>
#include "Mouse.h"
#include <Keyboard.h>
//--------------------------------------------------------------------------------------------------------


//------------------DEFINES------------------------------------------------------
//module addresses
#define NANO_I2C_ADDRESS 8
#define SCREEN_ADDRESS 0x3C 

//delays for the key actuation
#define INITIAL_DELAY 250
#define REPEAT_DELAY 5

//custom keys for mouse functions
#define MOUSE_LEFT_CLICK 0xFF
#define MOUSE_RIGHT_CLICK 0xFE
#define MOUSE_SCROLL_UP 0xFD
#define MOUSE_SCROLL_DOWN 0xFC

//custom keys
#define KEY_FUNCTION 0xFB
#define KEY_CHEVRON_L 236
#define KEY_CHEVRON_R 236
#define KEY_SCREENSHOT 0xFA
#define KEY_FUN 0xF9

//customs keys for module control
#define KEY_MOD_1 0xF8  //deply arm (servo) for mouse charge
#define KEY_MOD_2 0xF7  //retract arm for mouse charge
#define KEY_MOD_3 0xF6  //cycle between Clock, AV-RK MK2 logo, WPM/CPM count, and Heart rate monitor (smol OLED screen)/
#define KEY_MOD_4 0xF5  //cycle between compact display mode (one line for RTC time, one for wpm, one for temperature, one for humidity), normal display mode (just the temps and humidity) and fun mode (just displays random things "hollywood" style)
#define KEY_MOD_5 0xF4  //not assigned
#define KEY_MOD_6 0xF3  //not assigned
//---------------------------------------------
//------------------PCA OBJECTS----------------
PCA9505_06 NUMPAD;
PCA9505_06 LEFT;
PCA9505_06 RIGHT;
//---------------------------------------------

//------------------I2C OBJECTS----------------
TwoWire &ServoControllerBus = Wire;
//---------------------------------------------

//--------------------VARS---------------------
const uint8_t numKeys = 40; 
const int DEBOUNCE_DELAY = 200;


char keyMapNUMPAD[numKeys] = {
  KEY_PRINT_SCREEN, KEY_SCROLL_LOCK, KEY_PAUSE, KEY_NUM_LOCK, KEY_KP_SLASH, KEY_KP_ASTERISK, KEY_KP_MINUS, KEY_F13,
  KEY_INSERT, KEY_HOME, KEY_PAGE_UP, KEY_KP_7, KEY_KP_8, KEY_KP_9, KEY_KP_PLUS, KEY_F13,
  KEY_DELETE, KEY_END, KEY_PAGE_DOWN, KEY_KP_4, KEY_KP_5, KEY_KP_6, KEY_KP_PLUS, KEY_F13,
  KEY_F13, KEY_UP_ARROW, KEY_F13, KEY_KP_1, KEY_KP_2, KEY_KP_3, KEY_KP_ENTER, KEY_F13,
  KEY_LEFT_ARROW, KEY_DOWN_ARROW, KEY_RIGHT_ARROW, KEY_KP_0, KEY_KP_0, KEY_KP_ENTER, KEY_KP_DOT, KEY_F13
};
char keyMapNUMPADALT[numKeys] = {
  KEY_PRINT_SCREEN, KEY_SCROLL_LOCK, KEY_PAUSE, KEY_NUM_LOCK, KEY_KP_SLASH, KEY_KP_ASTERISK, KEY_KP_MINUS, KEY_F13,
  KEY_INSERT, KEY_HOME, KEY_PAGE_UP, KEY_KP_7, KEY_KP_8, KEY_KP_9, KEY_KP_PLUS, KEY_F13,
  KEY_DELETE, KEY_END, KEY_PAGE_DOWN, KEY_MOD_4, KEY_MOD_5, KEY_MOD_6, KEY_KP_PLUS, KEY_F13,
  KEY_F13, KEY_UP_ARROW, KEY_F13, KEY_MOD_1, KEY_MOD_2, KEY_MOD_3, KEY_KP_ENTER, KEY_F13,
  KEY_LEFT_ARROW, KEY_DOWN_ARROW, KEY_RIGHT_ARROW, KEY_KP_0, KEY_KP_0, KEY_KP_ENTER, KEY_KP_DOT, KEY_F13
};
char keyMapLEFT[numKeys] = {
  KEY_ESC, '1', '2', '3', '4', '5', '6', KEY_F13,
  KEY_TAB, 'q', 'w', 'e', 'r', 't', '`' /*KEY_SUPERSCRIPT_TWO*/, KEY_F13,
  KEY_CAPS_LOCK, 'a', 's', 'd', 'f', 'g', MOUSE_LEFT_CLICK /*'CLIC GAUCHE'*/, KEY_F13,
  KEY_LEFT_SHIFT, KEY_CHEVRON_L, 'z', 'x', 'c', 'v', MOUSE_RIGHT_CLICK /*'CLIC DROIT'*/, KEY_F13,
  KEY_LEFT_CTRL, KEY_LEFT_GUI, KEY_LEFT_ALT, KEY_F13 /* FONCTION*/, KEY_SCREENSHOT /*SCREENSHOT*/, ' ', KEY_RETURN, KEY_F13
};
char keyMapLEFTALT[numKeys] = {
  KEY_ESC, KEY_F1, KEY_F2, KEY_F3, KEY_F4, KEY_F5, KEY_F6, KEY_F13,
  KEY_TAB, 'q', 'w', 'e', 'r', 't', '`' /*KEY_SUPERSCRIPT_TWO*/, KEY_F13,
  KEY_CAPS_LOCK, 'a', 's', 'd', KEY_FUN, 'g', MOUSE_SCROLL_UP /*'CLIC GAUCHE'*/, KEY_F13,
  KEY_LEFT_SHIFT, KEY_F13 /*'chevron'*/, 'z', 'x', 'c', 'v', MOUSE_SCROLL_DOWN /*'CLIC DROIT'*/, KEY_F13,
  KEY_LEFT_CTRL, KEY_LEFT_GUI, KEY_LEFT_ALT, KEY_F13 /* FONCTION*/, KEY_F13 /*SCREENSHOT*/, ' ', KEY_RETURN, KEY_F13
};
char keyMapRIGHT[numKeys] = {
  '7', '8', '9', '0', '-', '=', '[', KEY_F13,
  KEY_F13, 'y', 'u', 'i', 'o', 'p', ']', KEY_F13,
  KEY_BACKSPACE, 'h', 'j', 'k', 'l', ';', '\'', KEY_F13,
  KEY_DELETE, 'b', 'n', 'm', ',', '.', '/', KEY_F13,
  KEY_RETURN, ' ', KEY_RIGHT_ALT, KEY_RIGHT_GUI, KEY_MENU, KEY_RIGHT_CTRL, '\\', KEY_F13

};
char keyMapRIGHTALT[numKeys] = {
  KEY_F7, KEY_F8, KEY_F9, KEY_F10, KEY_F11, KEY_F12, '[', KEY_F13,
  KEY_F13, 'y', 'u', KEY_UP_ARROW, 'o', 'p', ']', KEY_F13,
  KEY_BACKSPACE, 'h', KEY_LEFT_ARROW, KEY_DOWN_ARROW, KEY_RIGHT_ARROW, ';', '\'', KEY_F13,
  KEY_DELETE, 'b', 'n', 'm', ',', '.', '/', KEY_F13,
  KEY_RETURN, ' ', KEY_RIGHT_ALT, KEY_F13, KEY_F13, KEY_F13, '\\', KEY_F13
};

bool keyStateNP[numKeys] = { 0 };
bool keyStateL[numKeys] = { 0 };
bool keyStateR[numKeys] = { 0 };

bool isShiftPressed = false;
bool isCapsLockOn = false;
bool initialDelayPassed = false;
bool funTypingModeActive = false; 

unsigned long lastPressTime;
unsigned long lastToggleTime = 0;
uint8_t lastKeyPressed = 255;

uint8_t mouseSpeed = 7;
int16_t x = 0;
int16_t y = 0;

uint8_t countServoMod1 = 0;
bool armDeployed = false;
int keyMod2Counter = 0;
unsigned long lastPressTimeMod1 = 0;
unsigned long lastPressTimeMod2 = 0;
const long interval = 1000; 
//---------------------------------------------


//------------------PROTOTYPES------------------
void checkKeys(PCA9505_06& expander, char* keyMap, char* funcKeyMap, bool* keyState, bool funcKeyPressed);
void chargingArmDeploy(bool servoCommand);
void updateTrackball();
//---------------------------------------------


//------------------FUNCTIONS------------------
/**
 * @brief void setup(), init function
*/
void setup() {
  Serial.begin(9600);
  NUMPAD.begin(0x23);
  LEFT.begin(0x22);
  RIGHT.begin(0x21);
  trackball.begin(0x0A);
  ServoControllerBus.begin();
  trackball.setRGBW(0, 0, 0, 255);

  for (uint8_t i = 0; i < numKeys; i++) {
    NUMPAD.pinMode(i, INPUT);
    LEFT.pinMode(i, INPUT);
    RIGHT.pinMode(i, INPUT);
  }

  Keyboard.begin();

  if (trackball.isConnected()) {
    Mouse.begin();
  } else {
    while (true) {
      delay(1000);
    }
  }
}
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

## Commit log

2023-07-25 initial commit, added numpad files
    [Corps42.stl, PCB_NUMPAD_AV-RK MK II_2023-07-25.pcbdoc, SKETCH.dxf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]
2023-07-26 V1, functionnal numpad code
    [left drawing.dxf]
2023-07-28 finished CAD, added trackball to code
    [AV-RK MK II.xlsx, PCB_RIGHT_AV-RK MK II_2023-07-27.pcbdoc, PCB_RIGHT_AV-RK MK II_2023-07-27.step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]
2023-08-02 fixed wrong file uploaded, oops
    [AVLABS_AV_RK_MKII.ino]
2023-08-10 fixed git, added modules, modified main firmware
    [AV-RK MK II.xlsx, Corps42.stl, PCB_NUMPAD_AV-RK MK II_2023-07-25.pcbdoc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]
2023-08-15 fixed broken firmware (for some reason) and added V2 of CAD
    [BOTTOM.stl, TOP.stl, bottom (1) (1).stl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]
2023-08-16 added mouse charging module link stl
    [link.stl]
2023-08-21 updated CAD for sensor module
    [top (3).stl]
2024-02-03 fixed shit
    [AV-RK MK II.xlsx]
2025-04-21 Update AVLABS_AV_RK_MKII.ino
    FINALLY FIXED THE "spam letter" ISSUE THAT RENDERED THE KB USELESS IN GAMES!!!!
    COMMENTED OUT THE DEBOUNCE FEATURE
    [AVLABS_AV_RK_MKII.ino]
2025-08-22 fixed charging arm bug; hardened comms between modules, added calibration logic
    [AVLABS_AV_RK_MKII.ino, mousechargemodule.ino]
2025-08-28 calibrated servo with correct enpoint values
    [mousechargemodule.ino]

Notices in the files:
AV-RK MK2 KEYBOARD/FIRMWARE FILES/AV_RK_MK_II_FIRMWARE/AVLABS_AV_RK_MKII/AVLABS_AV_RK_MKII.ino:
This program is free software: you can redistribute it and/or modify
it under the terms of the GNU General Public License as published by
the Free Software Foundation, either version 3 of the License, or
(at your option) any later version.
